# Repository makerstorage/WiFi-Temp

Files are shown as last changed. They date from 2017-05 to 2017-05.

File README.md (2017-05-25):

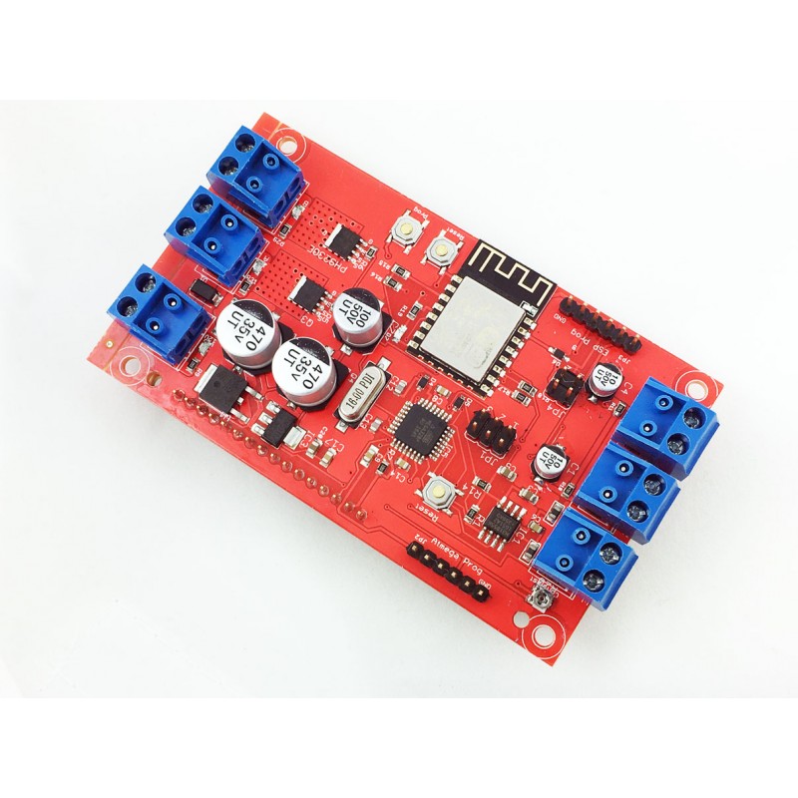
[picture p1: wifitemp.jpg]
WiFi Temperature Controller


**WiFi Temperature Controller**

For more details, check out the product page at

http://makerstorage.com/index.php?id_product=27&controller=product

MakerStorage invests time and resources providing this open source design, please support MakerStorage and open-source hardware by purchasing products from MakerStorage!

Designed by MakerStorage LLC.

Creative Commons Attribution, Share-Alike license, check https://creativecommons.org/licenses/by-sa/3.0/ for more information All text above must be included in any redistribution

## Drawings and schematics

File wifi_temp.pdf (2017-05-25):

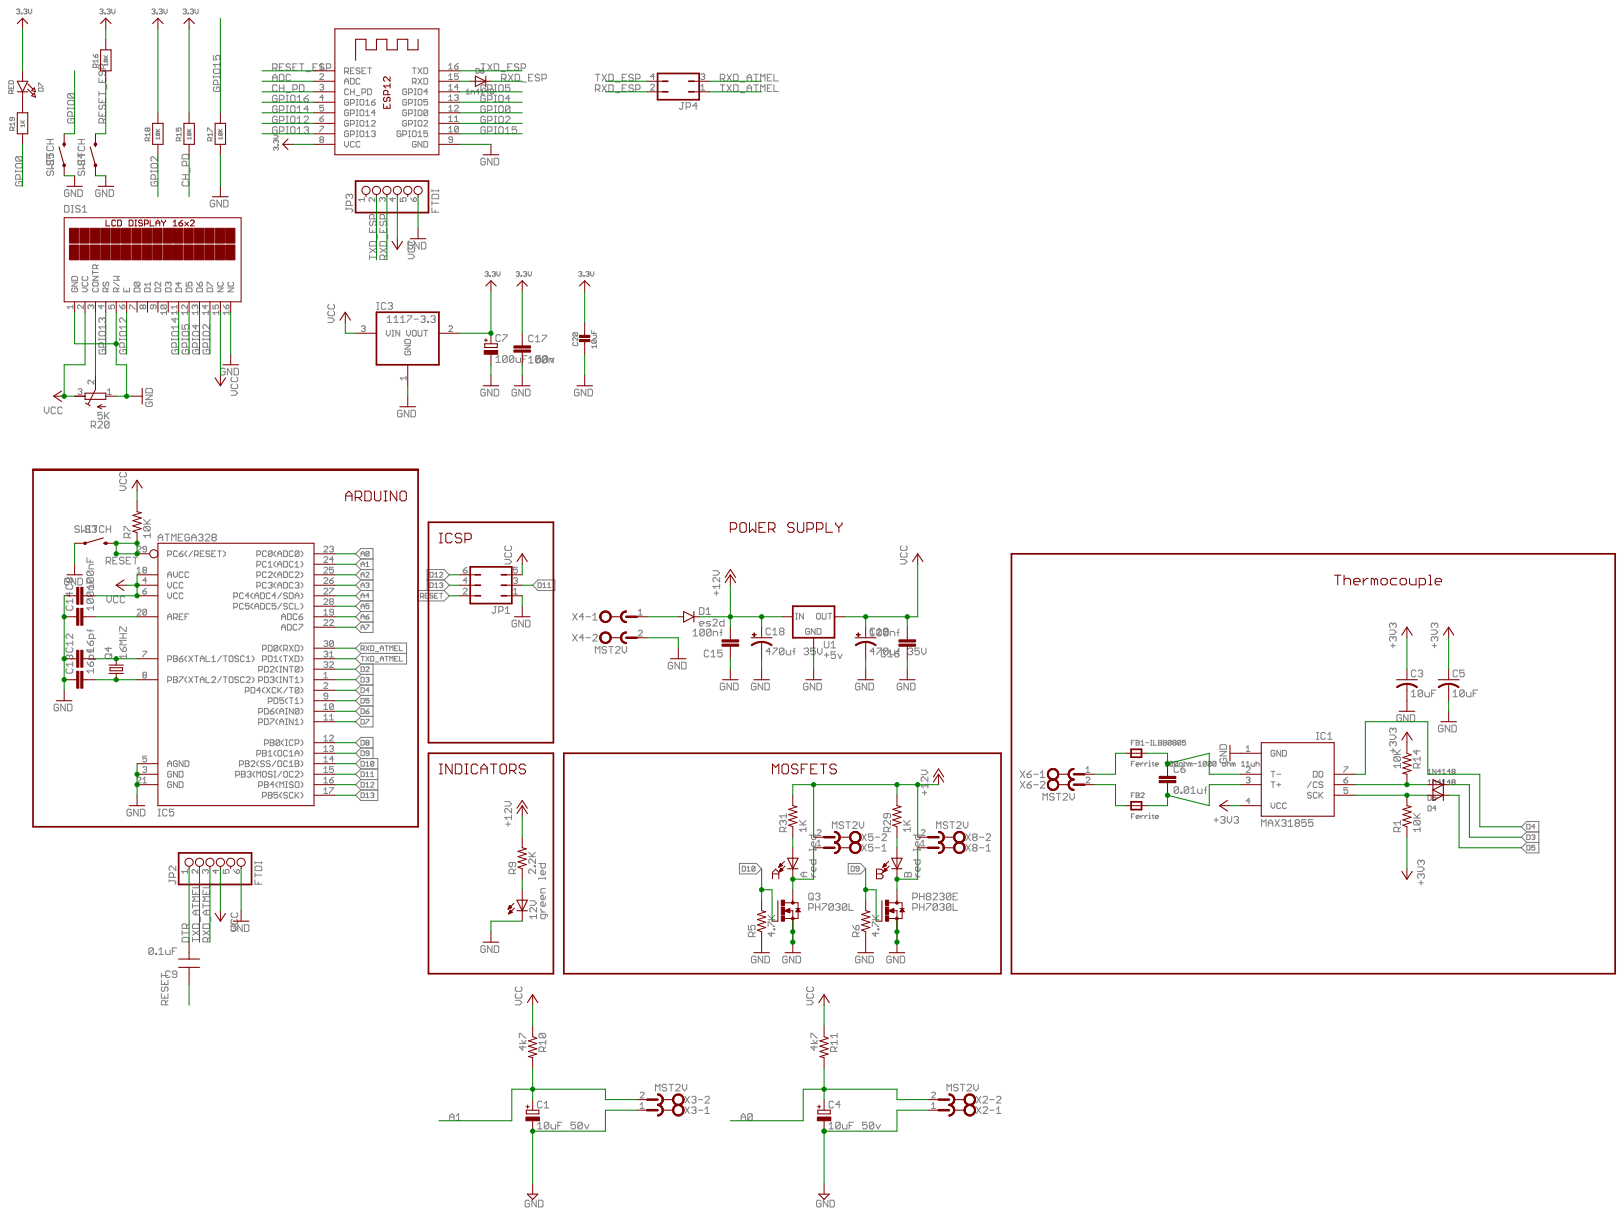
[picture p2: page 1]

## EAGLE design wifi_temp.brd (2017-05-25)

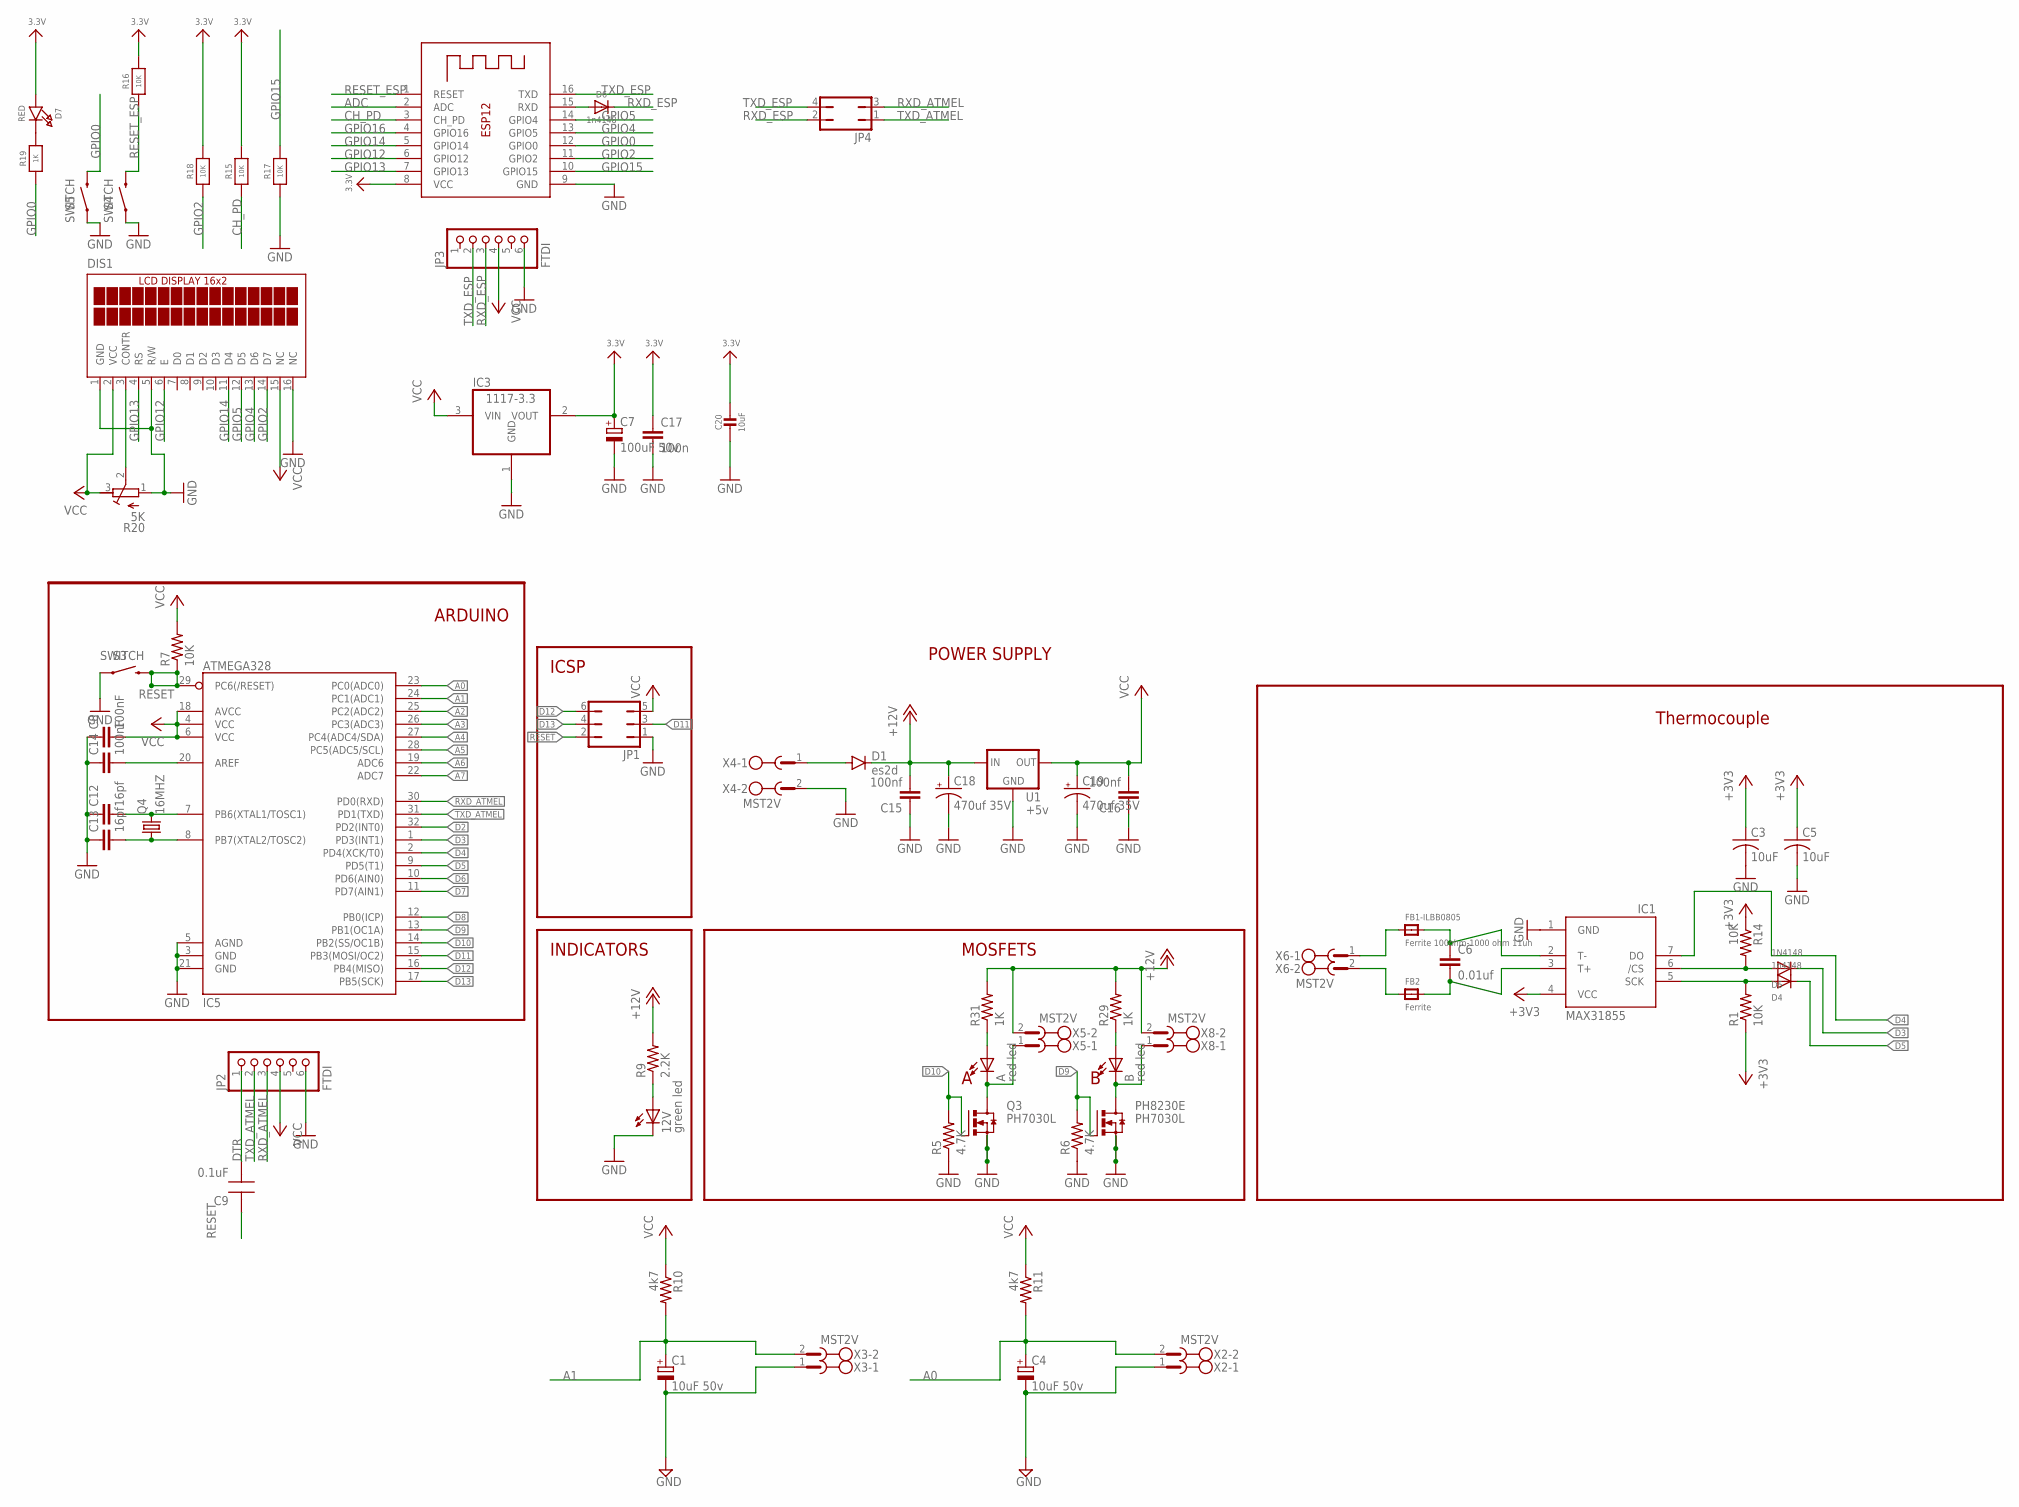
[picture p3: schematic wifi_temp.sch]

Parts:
12V: green led; LED-0805
A: red led; LED-0805
B: red led; LED-0805
C1, C4: 10uF 50v; SANYO-OSCON_SMD_B6
C3, C5: 10uF; C0805K
C6: 0.01uf; 0805
C7: 100uF 50v; SANYO-OSCON_SMD_E12
C8, C14: 100nF; 0805
C9: 0.1uF; CAP0805-NP
C12, C13: 16pf; 0805
C15, C16: 100nf; C0805
C17: 100n; C0805
C18, C19: 470uf 35V; PANASONIC_G
C20: 10uF; 0805-NO
D1: es2d; SMA-DIODE_ALT
D4: 1n4148; SOD-323F
D5: 1N4148; SOD-323F
D6: 1n4148; SOD-323
D7: RED; CHIPLED_0805_NOOUTLINE
DIS1: TUXGR_16X2_R2
FB1-ILBB0805: Ferrite 100ohm-1000 ohm 11uh; _0805
FB2: Ferrite; _0805
IC1: MAX31855; SO08
IC3: 1117-3.3; SOT223
IC5: ATMEGA328; TQFP32-08
JP1: JP3Q
JP2, JP3: FTDI; 1X06_ROUND_70
JP4: JP2Q
PH8230E: PH7030L; SOT669
Q3: PH7030L; SOT669
Q4: 16MHZ; SM49
R1, R14: 10K; R0805
R5, R6: 4.7K; 0805
R7: 10K; 0805
R9: 2.2K; 0805
R10, R11: 4k7; 0805
R15, R16, R17, R18: 10K; 0805-NO
R19: 1K; 0805-NO
R20: 5K; RTRIM3103
R29, R31: 1K; 0805
S3, S4, S5: SWITCH; TACTILE-SWITCH-SMD
U1: +5v; TO-252
X2, X3, X4, X5, X6, X8: MST2V; MSTBV2
X7: ESP-12F; ESP-12

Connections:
3.3V: C3.1, C5.1, C7.+, C17.1, C20.1, D7.A, IC1.4 (VCC), IC3.2 (VOUT), R1.1, R14.1, R15.2, R16.2, R18.2, X7.8 (VCC)
+12V: C15.2, C18.+, D1.C, R9.2, R29.2, R31.2, U1.1 (IN), X5.2, X8.2
A0: C4.+, IC5.23 (PC0(ADC0)), R11.2, X2.2
A1: C1.+, IC5.24 (PC1(ADC1)), R10.2, X3.2
A2: IC5.25 (PC2(ADC2))
A3: IC5.26 (PC3(ADC3))
A4: IC5.27 (PC4(ADC4/SDA))
A5: IC5.28 (PC5(ADC5/SCL))
A6: IC5.19 (ADC6)
A7: IC5.22 (ADC7)
ADC: X7.2 (ADC)
APWR: A.C, Q3.MB (D), X5.1
BPWR: B.C, PH8230E.MB (D), X8.1
CH_PD: R15.1, X7.3 (CH_PD)
CS: D5.A, IC1.6 (/CS), R14.2
D2: IC5.32 (PD2(INT0))
D3: D5.C, IC5.1 (PD3(INT1))
D4: IC1.7 (DO), IC5.2 (PD4(XCK/T0))
D5: D4.C, IC5.9 (PD5(T1))
D6: IC5.10 (PD6(AIN0))
D7: IC5.11 (PD7(AIN1))
D8: IC5.12 (PB0(ICP))
D9: IC5.13 (PB1(OC1A)), PH8230E.4 (G), R6.2
D10: IC5.14 (PB2(SS/OC1B)), Q3.4 (G), R5.2
D11: IC5.15 (PB3(MOSI/OC2)), JP1.3
D12: IC5.16 (PB4(MISO)), JP1.6
D13: IC5.17 (PB5(SCK)), JP1.4
DTR: C9.2, JP2.1
GND: 12V.C, C1.-, C3.2, C4.-, C5.2, C7.-, C8.1, C12.1, C13.1, C14.1, C15.1, C16.1, C17.2, C18.-, C19.-, C20.2, DIS1.1 (GND), DIS1.5 (R/W), DIS1.16 (NC), IC1.1 (GND), IC3.1 (GND), IC5.3 (GND), IC5.5 (AGND), IC5.21 (GND), JP1.1, JP2.6, JP3.6, PH8230E.1 (S), PH8230E.2 (S), PH8230E.3 (S), Q3.1 (S), Q3.2 (S), Q3.3 (S), R5.1, R6.1, R17.1, R20.1 (A), S3.1, S3.2 (1), S4.1, S4.2 (1), S5.1, S5.2 (1), U1.3 (GND), X2.1, X3.1, X4.2, X7.9 (GND)
GPIO0: R19.1, S5.3 (2), S5.4 (2), X7.12 (GPIO0)
GPIO2: DIS1.14 (D7), R18.1, X7.11 (GPIO2)
GPIO4: DIS1.13 (D6), X7.13 (GPIO5)
GPIO5: DIS1.12 (D5), X7.14 (GPIO4)
GPIO12: DIS1.6 (E), X7.6 (GPIO12)
GPIO13: DIS1.4 (RS), X7.7 (GPIO13)
GPIO14: DIS1.11 (D4), X7.5 (GPIO14)
GPIO15: R17.2, X7.10 (GPIO15)
GPIO16: X7.4 (GPIO16)
unnamed: FB1-ILBB0805.1, X6.1
unnamed: C6.2, FB2.2, IC1.3 (T+)
unnamed: D1.A, X4.1
unnamed: DIS1.3 (CONTR), R20.2 (S)
unnamed: C6.1, FB1-ILBB0805.2, IC1.2 (T-)
unnamed: FB2.1, X6.2
unnamed: D7.C, R19.2
unnamed: D6.A, X7.15 (RXD)
unnamed: C14.2, IC5.20 (AREF)
unnamed: 12V.A, R9.1
unnamed: C12.2, IC5.7 (PB6(XTAL1/TOSC1)), Q4.2
unnamed: C13.2, IC5.8 (PB7(XTAL2/TOSC2)), Q4.1
unnamed: A.A, R31.1
unnamed: B.A, R29.1
RESET: C9.1, IC5.29 (PC6(/RESET)), JP1.2, R7.1, S3.3 (2), S3.4 (2)
RESET_ESP: R16.1, S4.3 (2), S4.4 (2), X7.1 (RESET)
RXD_ATMEL: IC5.30 (PD0(RXD)), JP2.3, JP4.3
RXD_ESP: D6.C, JP3.3, JP4.2
SCK: D4.A, IC1.5 (SCK), R1.2
TXD_ATMEL: IC5.31 (PD1(TXD)), JP2.2, JP4.1
TXD_ESP: JP3.2, JP4.4, X7.16 (TXD)
VCC: C8.2, C16.2, C19.+, DIS1.2 (VCC), DIS1.15 (NC), IC3.3 (VIN), IC5.4 (VCC), IC5.6 (VCC), IC5.18 (AVCC), JP1.5, JP2.4, JP3.4, R7.2, R10.1, R11.1, R20.3 (E), U1.2 (OUT)

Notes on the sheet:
MOSFETS
ICSP
ARDUINO
INDICATORS
POWER SUPPLY
Thermocouple

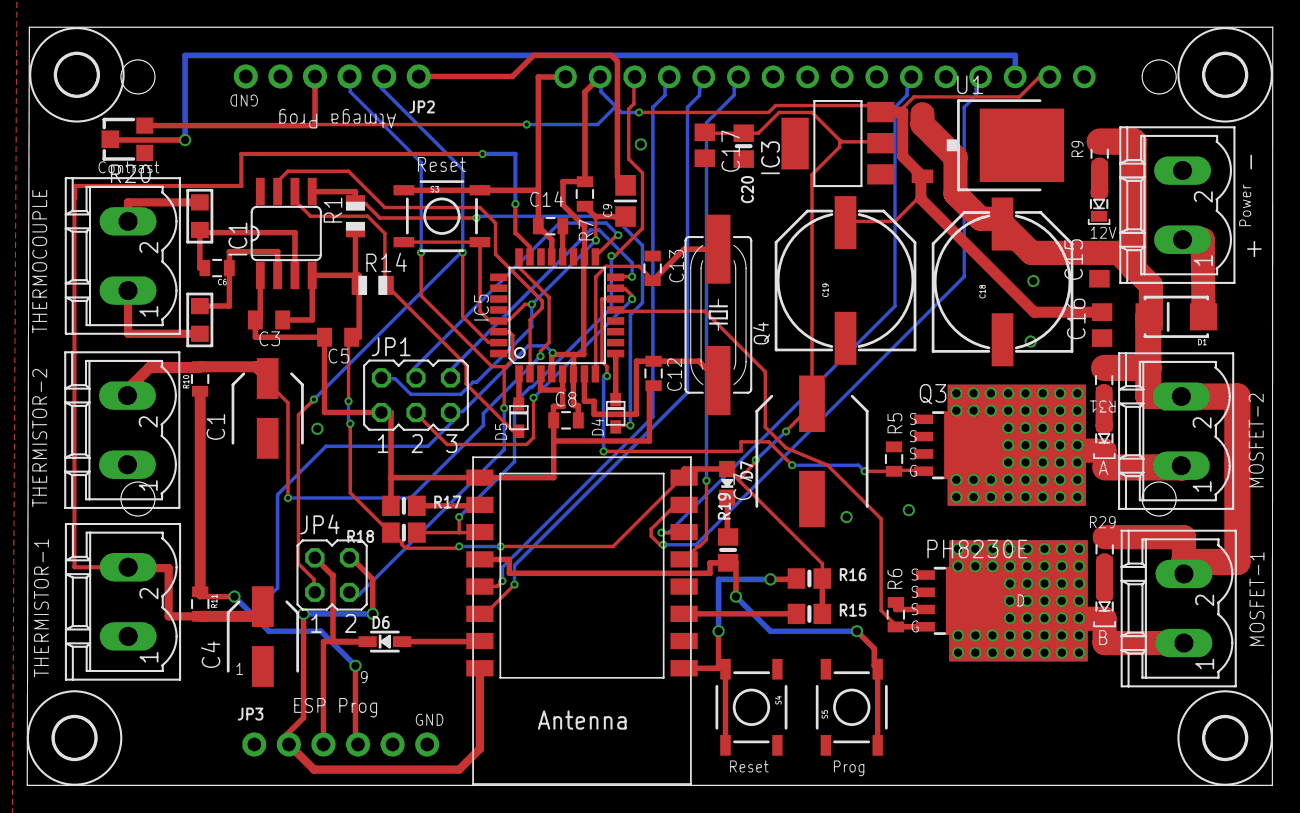
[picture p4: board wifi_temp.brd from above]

Board: 2 copper layers, 91.5 x 55.7 mm, 69 parts (1 on the bottom side), 48 nets.

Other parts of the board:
U$1, U$2, U$3, U$4: 3,0

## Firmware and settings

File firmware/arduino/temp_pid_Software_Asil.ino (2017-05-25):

#include <PID_v1.h>
#include <ArduinoJson.h>
#include <Wire.h>
#include "Adafruit_LEDBackpack.h"
#include "Adafruit_GFX.h"
#include <PID_v1.h>


#include <SPI.h>
#include "Adafruit_MAX31855.h"

#define MAXDO   4
#define MAXCS   3
#define MAXCLK  5

// initialize the Thermocouple
Adafruit_MAX31855 thermocouple(MAXCLK, MAXCS, MAXDO);

// Thermistor lookup table for RepRap Temperature Sensor Boards (http://make.rrrf.org/ts)
// Made with createTemperatureLookup.py (http://svn.reprap.org/trunk/reprap/firmware/Arduino/utilities/createTemperatureLookup.py)
// ./createTemperatureLookup.py --r0=100000 --t0=25 --r1=0 --r2=4700 --beta=4066 --max-adc=1023
// r0: 100000
// t0: 25
// r1: 0
// r2: 4700
// beta: 4066
// max adc: 1023
#define NUMTEMPS 20
short temptable[NUMTEMPS][2] = {
   {1, 841},
   {54, 255},
   {107, 209},
   {160, 184},
   {213, 166},
   {266, 153},
   {319, 142},
   {372, 132},
   {425, 124},
   {478, 116},
   {531, 108},
   {584, 101},
   {637, 93},
   {690, 86},
   {743, 78},
   {796, 70},
   {849, 61},
   {902, 50},
   {955, 34},
   {1008, 3}
};


/*
 * Nuri Erginer
 * <http://makerstorage.com/>
 * Wifi PID Controller Ver 1
 * PID Controller for CNC 2 Printer 3D Conversion
 */



#define DEBUG


//Mosfet Outputs
#define ExtruderOutput 9  //mosfet 1 connected to digital 9
#define BedOutput 10 //mosfet 2 connected to digital 10



//Sensors
int ExtruderSensor =-1; //0=Thermistor1  1=Thermistor2  3=Thermocouple
int BedSensor =-1;




long Status_previousMillis = 0;        // will store last time status updated
long Status_interval = 2500;           // interval at which status send (milliseconds)

long Temp_previousMillis =0;
long Temp_interval = 500;

#define TEMPERATURE_SAMPLES 10
#define TEMP_UPDATE_INTERVAL 200
unsigned long temp_prev_time;

double Current_Extruder_Temp = 0;
double Set_Extruder_Temp = 185;

double Current_Bed_Temp = 0;
double Set_Bed_Temp = 75;

String jsonIn = "";

double OutputValueExtruder;
double OutputValueBed;

double KP_Extruder = 400;
double KI_Extruder = 0.08;
double KD_Extruder = 400;

double KP_Bed = 400;
double KI_Bed = 0.08;
double KD_Bed = 400;


//sending status data to esp in json format
StaticJsonBuffer<200> jsonBuffer;
JsonObject& CurStatus = jsonBuffer.createObject();

void setup() {

  ReadFromEprom();
  Serial.begin(9600);
  
  pinMode(ExtruderOutput, OUTPUT);
  digitalWrite(ExtruderOutput, LOW);

  pinMode(BedOutput, OUTPUT);
  digitalWrite(BedOutput, LOW);

  initPID();

}



void loop() {
//ExtruderSensor =0; //0=Thermistor1  1=Thermistor2 2=Thermocouple
//BedSensor =1;
//Set_Extruder_Temp =55;  

  statusUpdate();
  tempUpdate();
  serialUpdate();



}//loop


void statusUpdate(){
  //Atmel sending current values about temperature management
  
  if (millis() - Status_previousMillis > Status_interval) 
  {
    Status_previousMillis = millis();   // PID update rate
    CurStatus["ST1"] = Set_Extruder_Temp;
    CurStatus["ST2"] = Set_Bed_Temp;
    CurStatus["CT1"] = Current_Extruder_Temp;
    CurStatus["CT2"] = Current_Bed_Temp;
    CurStatus["O1"] = OutputValueExtruder;
    CurStatus["O2"] = OutputValueBed;

    //send status data to esp
     CurStatus.printTo(Serial);
     Serial.println("");
     

  }//if millis 
}

void tempUpdate(){
   if (millis() - Temp_previousMillis > Temp_interval) 
   {
    Temp_previousMillis = millis();   // PID update rate
    Manage_Temperatures ();

   }// if milis
}

void serialUpdate(){
  /*
  ESP send serial data to us when settings web page updated
  below code handle the comming json data and write them to
  approprate vars.
 */
    while (Serial.available()) {
      // get the new byte:
     //{"pid1_sensor":"0","pid1_settemp":"55","pid1_P":"400","pid1_I":"0.08","pid1_D":"400","pid2_sensor":"2","pid2_settemp":"60","pid2_P":"400","pid2_I":"0.08","pid2_D":"400"}
     
     jsonIn = Serial.readStringUntil('\n');  //read json 

   //  Serial.println(jsonIn);
     
     StaticJsonBuffer<300> jsonBuffer;
     JsonObject& root = jsonBuffer.parseObject(jsonIn);

     if (root.success()) {
     
       ExtruderSensor = String(root["pid1_sensor"].asString()).toInt();
       BedSensor = String(root["pid2_sensor"].asString()).toInt();

//       Serial.println(ExtruderSensor);
//       Serial.println(BedSensor);
//       Serial.println("------");
       
       Set_Extruder_Temp = String(root["pid1_settemp"].asString()).toFloat();
       Set_Bed_Temp = String(root["pid2_settemp"].asString()).toFloat();

//       Serial.println(Set_Extruder_Temp);
//       Serial.println(Set_Bed_Temp);
//       Serial.println("------");

       KP_Extruder = String(root["pid1_P"].asString()).toFloat();
       KP_Bed = String(root["pid2_P"].asString()).toFloat();

//       Serial.println(KP_Extruder);
//       Serial.println(KP_Bed);
//       Serial.println("------");

       KI_Extruder = String(root["pid1_I"].asString()).toFloat();
       KI_Bed = String(root["pid2_I"].asString()).toFloat();

 //      Serial.println(KI_Extruder);
//       Serial.println(KI_Bed);
//       Serial.println("------");

       KD_Extruder = String(root["pid1_D"].asString()).toFloat();
       KD_Bed = String(root["pid2_D"].asString()).toFloat();

//       Serial.println(KD_Extruder);
//       Serial.println(KD_Bed);
//       Serial.println("------");
     
      Write2Eprom(); // the new settings must be written in eeprom
     }
    }//while
}

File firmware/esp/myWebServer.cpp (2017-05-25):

/*
myWebServer.cpp for esp8266

Copyright (c) 2016 David Paiva (david@nailbuster.com). All rights reserved.


This library is free software; you can redistribute it and/or
modify it under the terms of the GNU Lesser General Public
License as published by the Free Software Foundation; either
version 2.1 of the License, or (at your option) any later version.
This library is distributed in the hope that it will be useful,
but WITHOUT ANY WARRANTY; without even the implied warranty of
MERCHANTABILITY or FITNESS FOR A PARTICULAR PURPOSE.  See the GNU
Lesser General Public License for more details.
You should have received a copy of the GNU Lesser General Public
License along with this library; if not, write to the Free Software
Foundation, Inc., 51 Franklin St, Fifth Floor, Boston, MA  02110-1301  USA
*/

#include "myWebServer.h"

#include <ESP8266WiFi.h>
#include <WiFiClient.h>
#include <ESP8266WebServer.h>
#include <ESP8266mDNS.h>
#include <DNSServer.h>
#include <WiFiUdp.h>
#include <FS.h>
#include <ArduinoJson.h> 
#include "htmlEmbed.h"
#include <TimeLib.h>
#include <LiquidCrystal.h>


#ifdef ALLOW_IDEOTA
 #include <ArduinoOTA.h>
#endif // ALLOW_IDEOTA

extern LiquidCrystal lcd;

extern int ST1; //Set_Extruder_Temp
extern int CT1; //Current_Extruder_Temp
extern float O1; // OutputValueExtruder;
extern int ST2; //Set_Bed_Temp
extern int CT2; //Current_Bed_Temp
extern float O2; // OutputValueBed;

ESP8266WebServer server(80);
IPAddress apIP(192, 168, 4, 1);
DNSServer dnsServer;
bool dsnServerActive = false;
String ConfigUsername="admin";   //used for webconfig username admin
String ConfigPassword="";        //used for webconfig username admin
File fsUploadFile;


//ntp stuffs
WiFiUDP UDPNTPClient;
unsigned long lastTimeCheck = 0;  //for timer to fire every sec
const int NTP_PACKET_SIZE = 48;
byte packetBuffer[NTP_PACKET_SIZE];
time_t prevDisplay = 0; // when the digital clock was displayed

MyWebServerClass MyWebServer;
String MyWebServerLog;



void handleIndex() {
  //send GZ version of embedded config
  server.sendHeader("Content-Encoding", "gzip");
  server.send_P(200, "text/html", PAGE_INDEX, sizeof(PAGE_INDEX));
}

void handleWifiConfig() {
  //send GZ version of embedded config
  server.sendHeader("Content-Encoding", "gzip");
  server.send_P(200, "text/html", PAGE_WIFISETUP, sizeof(PAGE_WIFISETUP));
}


void handlePIDConfig() {
  //send GZ version of embedded config
  server.sendHeader("Content-Encoding", "gzip");
  server.send_P(200, "text/html", PAGE_PIDSETUP, sizeof(PAGE_PIDSETUP));
}

void sendPIDUpdate(String fname) {
  // pid.json file saved so we have to send this to atmel
  File file = SPIFFS.open(fname, "r");
  if (file) {
    Serial.println(file.readStringUntil('\n'));
    file.close();
  }
}


void handleDashBoard() { // we willsend dash board file
  //send GZ version of embedded config
  server.sendHeader("Content-Encoding", "gzip");
  server.send_P(200, "text/html", PAGE_DASHBOARD, sizeof(PAGE_DASHBOARD));
}

void handleAbout() { // we willsend dash board file
  //send GZ version of embedded config
  server.sendHeader("Content-Encoding", "gzip");
  server.send_P(200, "text/html", PAGE_ABOUT, sizeof(PAGE_ABOUT));
}

void handleDashJsonUpdate() {
  //dashboard data will be send to webpage from this function
  DebugPrintln("handleJsonUpdate");


  String InJson = "{\"ST1\":"+String(ST1)+
  ",\"ST2\":"+String(ST2)+
  ",\"CT1\":"+String(CT1)+
  ",\"CT2\":"+String(CT2)+
  ",\"O1\":"+String(O1)+
  ",\"O2\":"+String(O2)+"}";
  
//  server.streamFile(InJson, "application/json");
  server.send ( 200, "application/json",InJson);
}


// send an NTP request to the time server at the given address
void  sendNTPpacket(IPAddress &address)
{
	// set all bytes in the buffer to 0
	memset(packetBuffer, 0, NTP_PACKET_SIZE);
	// Initialize values needed to form NTP request
	// (see URL above for details on the packets)
	packetBuffer[0] = 0b11100011;   // LI, Version, Mode
	packetBuffer[1] = 0;     // Stratum, or type of clock
	packetBuffer[2] = 6;     // Polling Interval
	packetBuffer[3] = 0xEC;  // Peer Clock Precision
							 // 8 bytes of zero for Root Delay & Root Dispersion
	packetBuffer[12] = 49;
	packetBuffer[13] = 0x4E;
	packetBuffer[14] = 49;
	packetBuffer[15] = 52;
	// all NTP fields have been given values, now
	// you can send a packet requesting a timestamp:                 
	UDPNTPClient.beginPacket(address, 123); //NTP requests are to port 123
	UDPNTPClient.write(packetBuffer, NTP_PACKET_SIZE);
	UDPNTPClient.endPacket();
}


bool IsDst(int hour,int day, int month, int dow)  //north american dst  dow 0=SUN
{
	if (MyWebServer.daylight == false) return false; //option to disable DST

    //January, february, and december are out.
	if (month < 3 || month > 11) { return false; }
	//April to October are in
	if (month > 3 && month < 11) { return true; }
	int previousSunday = day - dow;
	//In march, we are DST if our previous sunday was on or after the 8th.
	if (month == 3) { return previousSunday >= 8; }
	//In november we must be before the first sunday to be dst.
	//That means the previous sunday must be before the 1st.
	return previousSunday <= 0;	
}


time_t getNtpTime()
{
	
	while (UDPNTPClient.parsePacket() > 0); // discard any previously received packets
	DebugPrintln("Transmit NTP Request");
	IPAddress timeServerIP;
	WiFi.hostByName(MyWebServer.ntpServerName.c_str(), timeServerIP);
	sendNTPpacket(timeServerIP);
	uint32_t beginWait = millis();
	while (millis() - beginWait < 1500) {
		int size = UDPNTPClient.parsePacket();
		if (size >= NTP_PACKET_SIZE) {
			DebugPrintln("Receive NTP Response");
			UDPNTPClient.read(packetBuffer, NTP_PACKET_SIZE);  // read packet into the buffer
			unsigned long secsSince1900;
			// convert four bytes starting at location 40 to a long integer
			secsSince1900 = (unsigned long)packetBuffer[40] << 24;
			secsSince1900 |= (unsigned long)packetBuffer[41] << 16;
			secsSince1900 |= (unsigned long)packetBuffer[42] << 8;
			secsSince1900 |= (unsigned long)packetBuffer[43];
			secsSince1900 = secsSince1900 - 2208988800UL + ((MyWebServer.timezone / 10) * SECS_PER_HOUR);
			if (IsDst(hour(secsSince1900),day(secsSince1900), month(secsSince1900), dayOfWeek(secsSince1900)-1)) secsSince1900 += 3600;  //add hour if DST			
			return secsSince1900;
		}
	}
	DebugPrintln("No NTP Response :-(");
	return 0; // return 0 if unable to get the time
}





// convert a single hex digit character to its integer value (from https://code.google.com/p/avr-netino/)
unsigned char h2int(char c)
{
	if (c >= '0' && c <= '9') {
		return((unsigned char)c - '0');
	}
	if (c >= 'a' && c <= 'f') {
		return((unsigned char)c - 'a' + 10);
	}
	if (c >= 'A' && c <= 'F') {
		return((unsigned char)c - 'A' + 10);
	}
	return(0);
}
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

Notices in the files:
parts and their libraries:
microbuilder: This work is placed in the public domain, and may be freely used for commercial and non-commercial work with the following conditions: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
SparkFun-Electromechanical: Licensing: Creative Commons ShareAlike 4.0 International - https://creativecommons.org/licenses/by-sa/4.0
